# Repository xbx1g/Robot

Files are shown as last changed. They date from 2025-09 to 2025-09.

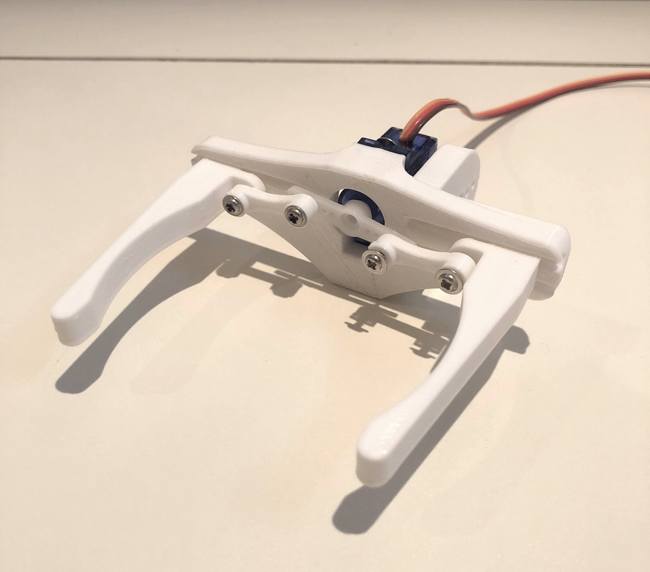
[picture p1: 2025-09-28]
3D_Modeli/VER2/linear-gripper-1.snapshot.4/Finished Build.jpg

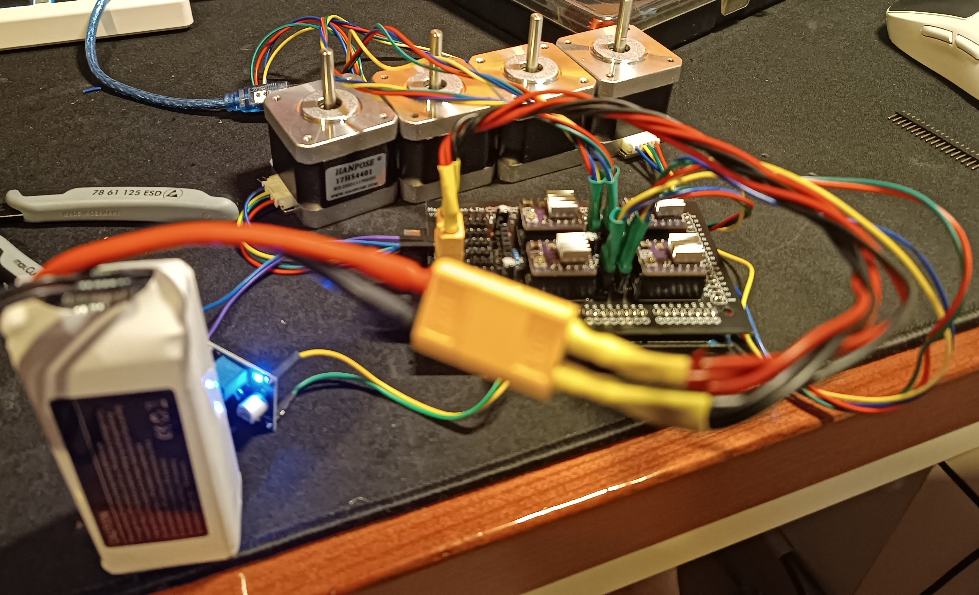
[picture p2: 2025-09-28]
Slike/final_test_baterija_3300mAh.jpg

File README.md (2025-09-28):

# 🤖 Robotic Arm with Mecanum Wheels

This project is a **final thesis** for the vocational matura exam.  
It is a mobile robot with **mecanum wheels** and a **robotic arm**, controllable via **Bluetooth** using a custom mobile app.  
The project combines **mechanical engineering, electronics, and programming** – from CAD design and 3D printing, to PCB design, Arduino programming, and mobile app development.

---

## 📌 Features

- Omni-directional movement with **mecanum wheels**  
- **Robotic arm** with multiple degrees of freedom (servo motors)  
- Custom-designed **PCB** for component management  
- **Arduino Mega 2560** as the main controller  
- Control via **Bluetooth module HC-05** and a mobile app (MIT App Inventor)  
- **3D-printed parts** made from PETG filament  
- Powered and tested with **11.1V 3300 mAh LiPo battery**  

---

## 🛠️ Components Used

- Arduino Mega 2560  
- Servo motors (MG996R, SG90)  
- Bipolar stepper motors + **DRV8825 drivers**  
- Bluetooth module **HC-05**  
- Voltage regulator **LM2596**  
- Custom-designed **PCB** (Eagle CAD)  
- 3D-printed parts (Autodesk Inventor + PrusaSlicer, Ender 3 S1 printer)  

---

## 📱 Mobile App

Developed with **MIT App Inventor**.  
Main features:  
- Control of chassis movement (forward/backward/left/right/diagonal)  
- Control of robotic arm (individual joints)  
- Save and execute movement sequences  
- Adjust motor speeds  

---

## 💻 Arduino Code

The Arduino firmware is organized into several modules:  
- **Main program** (initialization, Bluetooth connection)  
- **Chassis movement control**  
- **Robotic arm control**  
- **Movement sequence storage and execution**  
- **Battery voltage monitoring** with LED warning  

---

## 🚀 Getting Started

1. Assemble the robot (chassis, arm, PCB, and wiring).  
2. Upload the Arduino code to **Arduino Mega 2560**.  
3. Install the mobile app (APK) on your smartphone.  
4. Pair with the **HC-05 Bluetooth module**.  
5. Start controlling the robot and test the functionalities.  

---

## 📊 Testing Results

- Battery runtime: ~30 minutes  
- Stepper motor driver temperature after 30 minutes: **45–55 °C**  
- Robot successfully performs omni-directional movements and basic manipulation tasks  

---

## 🔮 Future Improvements

- Add **LCD display** for battery monitoring and step sequence display  
- Support for **Xbox / other Bluetooth controllers**  
- Further PCB optimization and cable management  

---

## 👤 Author

**Marko Koren**  
Mentor: **Peter Zoroja**  
Šolski center Nova Gorica, 2024

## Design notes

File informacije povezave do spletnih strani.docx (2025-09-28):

Spletne strani, informacije:

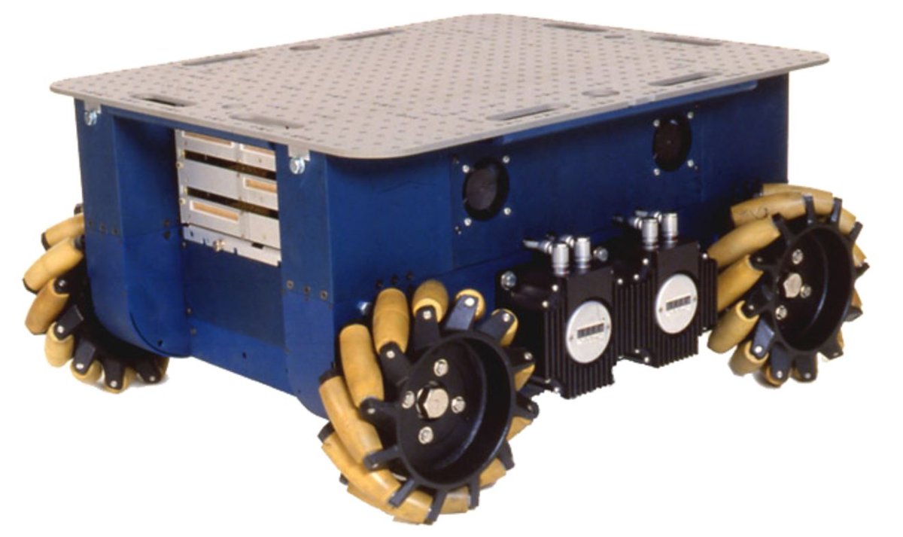
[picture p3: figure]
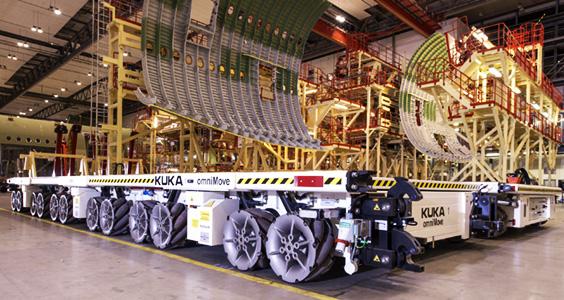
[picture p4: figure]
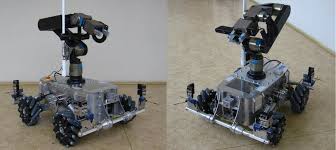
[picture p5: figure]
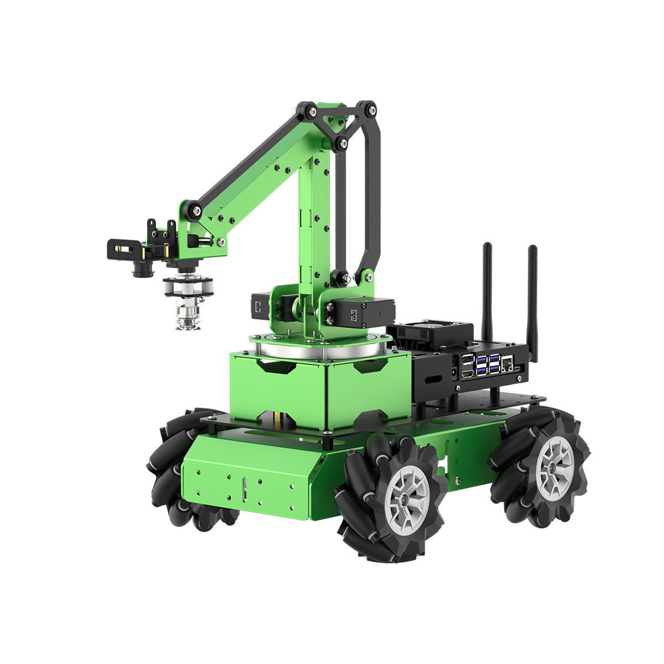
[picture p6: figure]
Hiwonder JetMax Pro JETSON NANO Robot Arm with Mecanum Wheel Chassis/

https://www.youtube.com/watch?v=noqBUEgyQ8A&t=275s

https://www.youtube.com/watch?v=83tVkgT89dM&t=549s

https://www.youtube.com/watch?v=8qtVhCtRoDY&t=21s

https://www.youtube.com/watch?v=Q3pCpVepCxk&t=608s

https://www.youtube.com/watch?v=LBNRGBY5zN8&t=453s&pp=ygUObWVjYW51bSB3aGVlbHM%3D

https://www.youtube.com/shorts/dnPcnVE-7ag

https://www.youtube.com/watch?v=I0Qm7qgqeLU

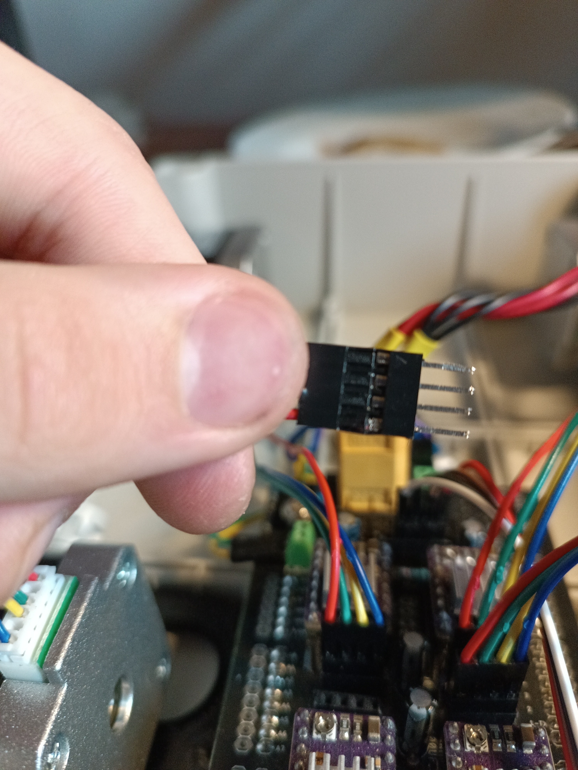
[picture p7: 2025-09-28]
Slike/Konektorj_stepper_motor.jpg

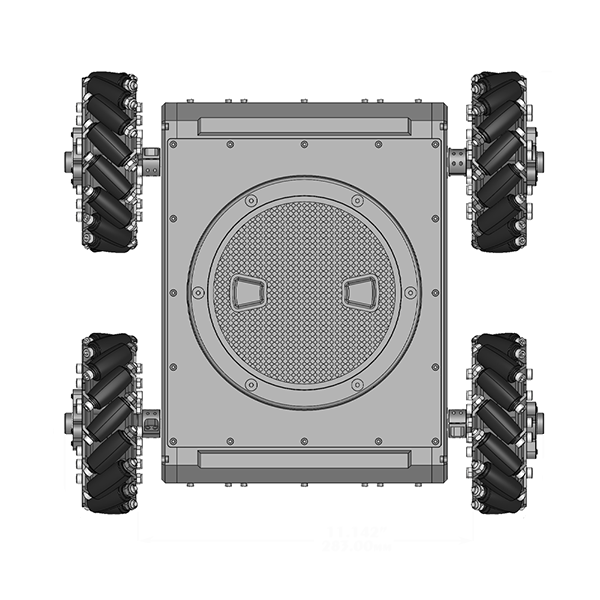
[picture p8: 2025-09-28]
Aplikacija/APP INVENTRO/ROVER.png

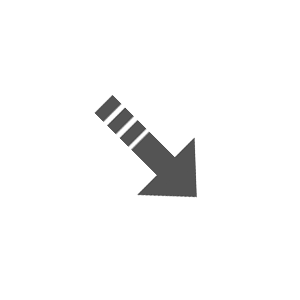
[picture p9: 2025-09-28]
Aplikacija/APP INVENTRO/desnodol.png

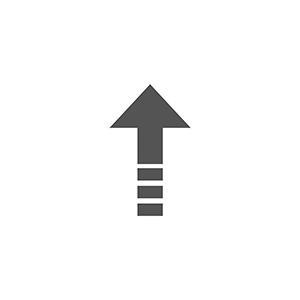
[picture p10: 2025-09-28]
Aplikacija/APP INVENTRO/puscica gor.png

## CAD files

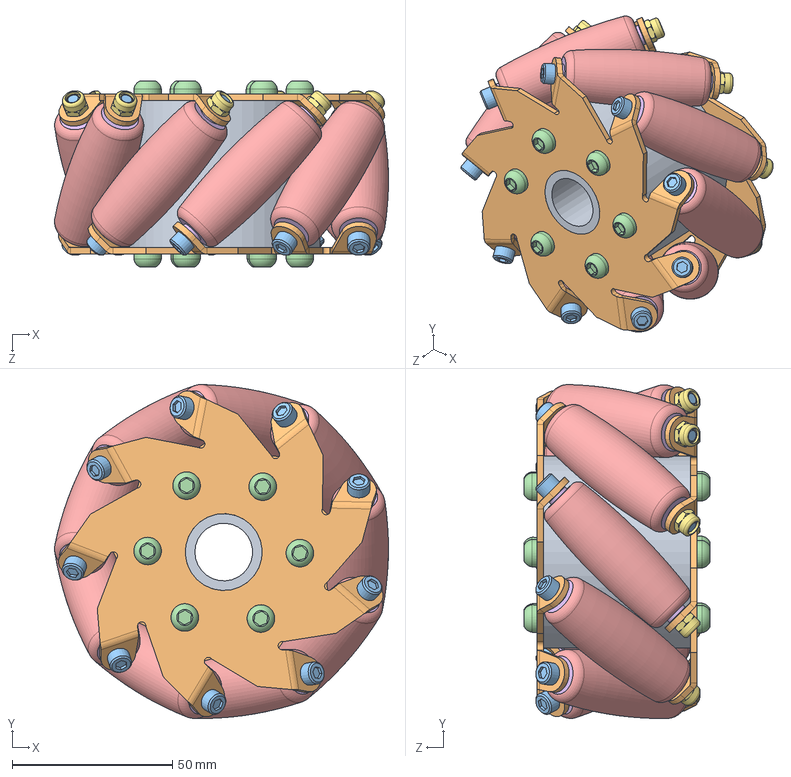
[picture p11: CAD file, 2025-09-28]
3D_Modeli/Robotska_roka/mecanum-wheel-diameter-100mm-right-1.snapshot.1/Mecanum Wheel (dia 100) Right/Assembly/Mecanum Wheel Assembly.SLDASM
104.2 x 104.2 x 58.0 mm
Shaft
Bolt (M3) x 9
Bolt (M5) x 12
Roller x 9
Roller Bracket x 18
torque nut 08_iso x 9

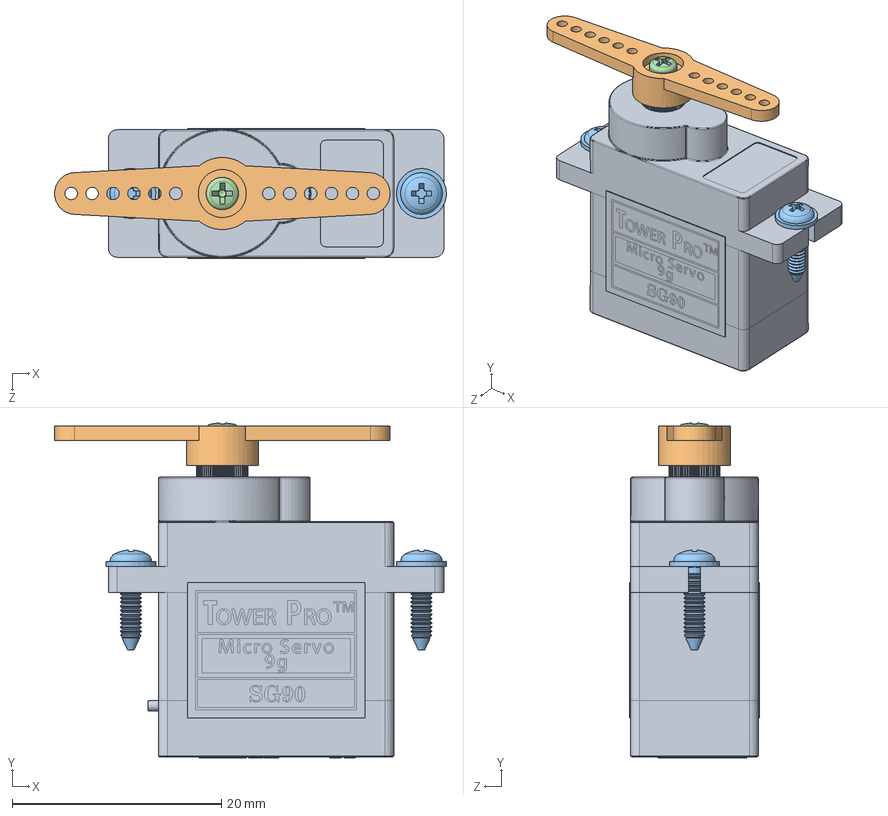
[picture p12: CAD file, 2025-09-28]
3D_Modeli/VER2/sg90-micro-servo-9g-tower-pro-1.snapshot.3/SG90 - Micro Servo 9g - Tower Pro.SLDASM
37.5 x 32.0 x 12.4 mm
SG90 - Micro Servo 9g - Tower Pro.1
SG90 - Micro Servo 9g - Tower Pro.3
SG90 - Micro Servo 9g - Tower Pro.5 x 2
SG90 - Micro Servo 9g - Tower Pro.6

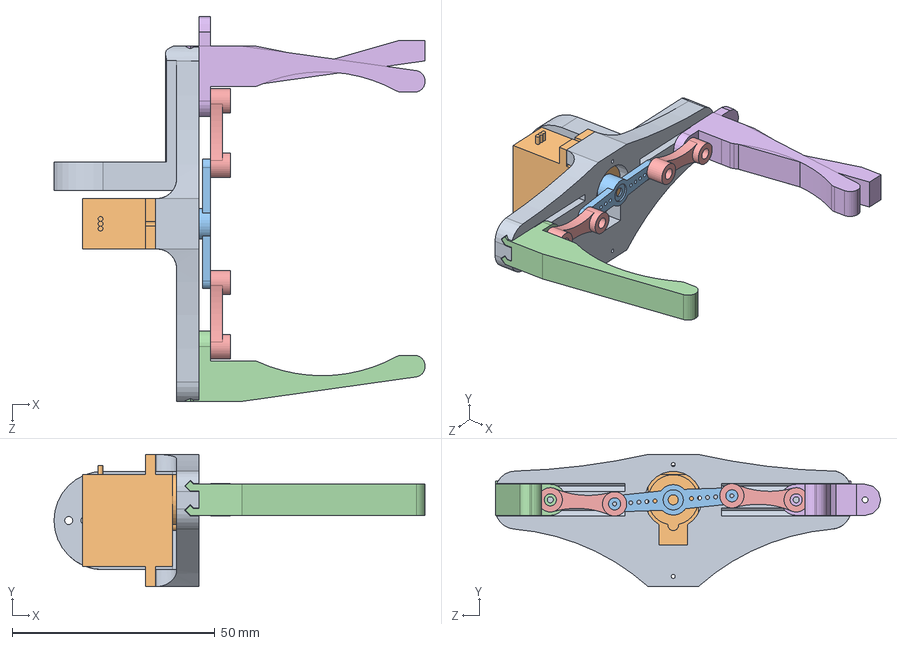
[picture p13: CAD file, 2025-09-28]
3D_Modeli/Robotska_roka/linear-gripper-1.snapshot.4/Linear Gripper.SLDASM
91.5 x 32.6 x 95.1 mm
Linear Base
Servo Micro
Horn
LGrip
Linear Link x 2
LGrip Mirror

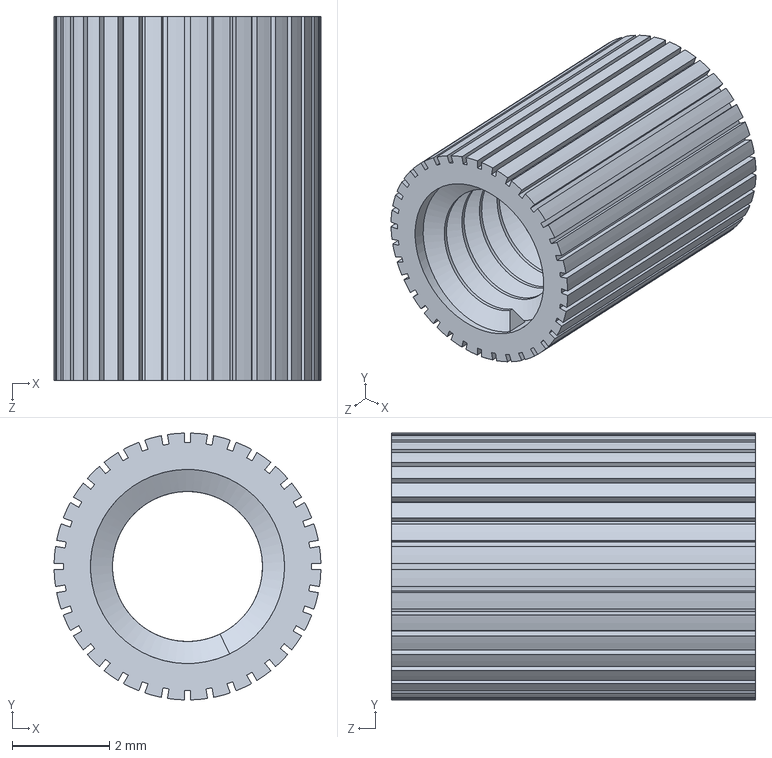
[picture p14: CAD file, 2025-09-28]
3D_Modeli/Robotska_roka/lemotech-ip67-junction-box-250-mm-x-150-mm-x-100-mm-1.snapshot.2/M4 Insert, LeMotech IP67 Junction Box, 250 mm x 150 mm x 100 mm.SLDPRT
5.50 x 5.50 x 7.50 mm

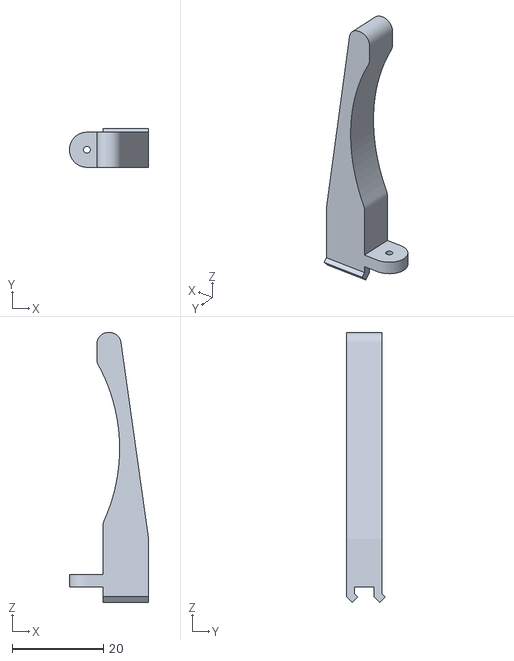
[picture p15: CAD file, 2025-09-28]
3D_Modeli/Robotska_roka/linear-gripper-1.snapshot.4/Linear Gripper/LGrip Mirror.stl
17.4 x 8.47 x 59.1

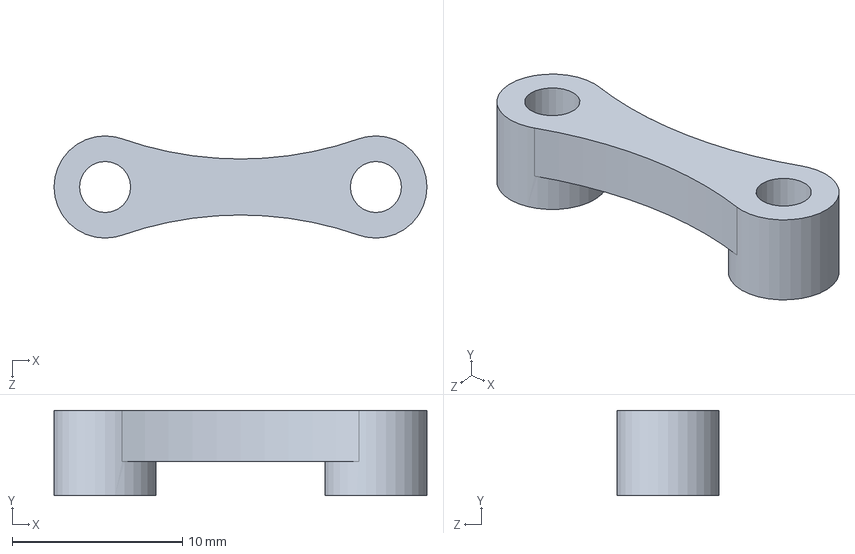
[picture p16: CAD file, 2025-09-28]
3D_Modeli/Robotska_roka/linear-gripper-1.snapshot.4/Linear Link.SLDPRT
21.9 x 5.00 x 6.00 mm

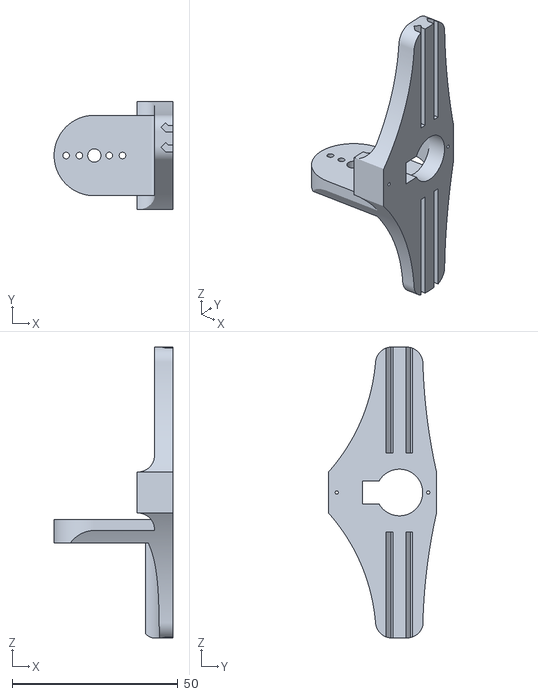
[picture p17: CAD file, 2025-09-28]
3D_Modeli/Robotska_roka/linear-gripper-1.snapshot.4/STL for 3D Printing/Linear Gripper - Linear Base-1.STL
35.8 x 32.6 x 87.8

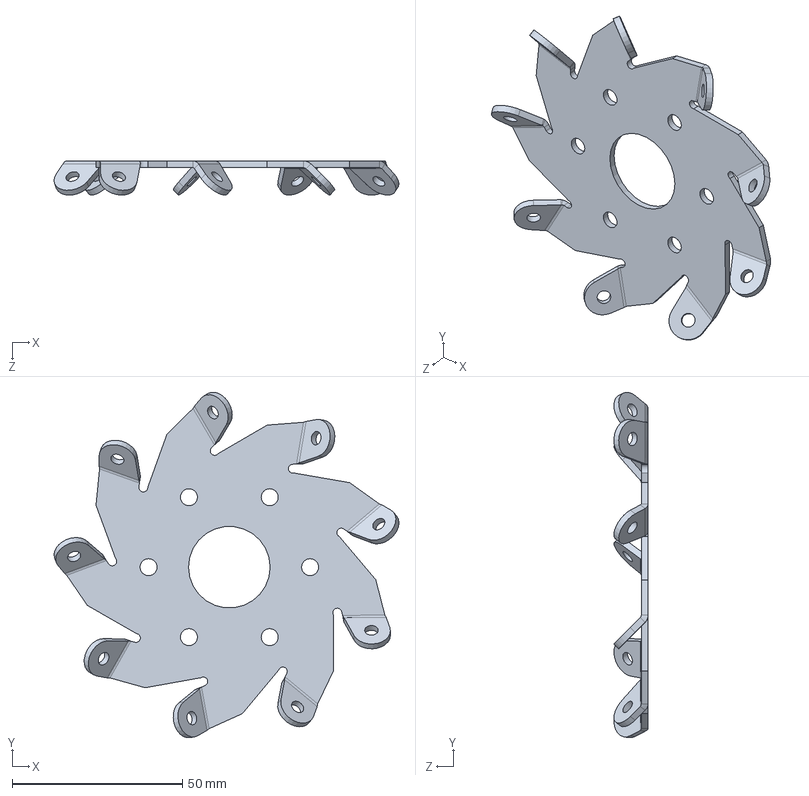
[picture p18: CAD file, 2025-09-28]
3D_Modeli/Robotska_roka/mecanum-wheel-diameter-100mm-right-1.snapshot.1/Mecanum Wheel (dia 100) Right/Components/Body.SLDPRT
101.4 x 101.6 x 10.1 mm

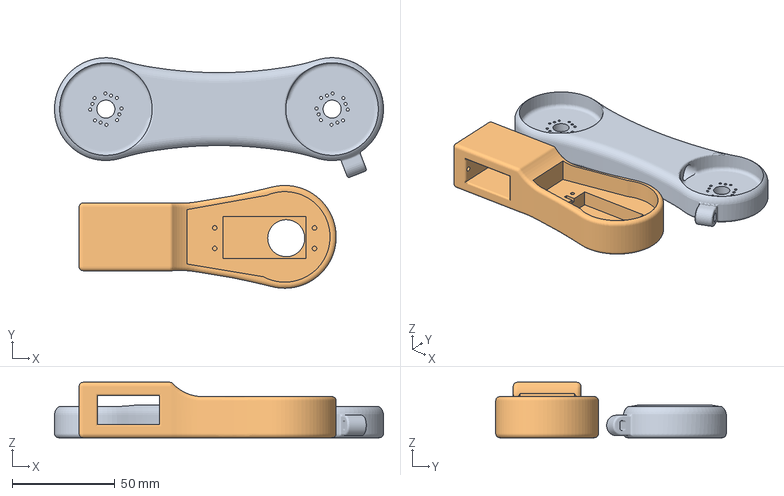
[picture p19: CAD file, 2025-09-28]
3D_Modeli/Robotska_roka/roka1.3mf
160.0 x 112.1 x 27.0 mm
roka1.stl
roka2.stl

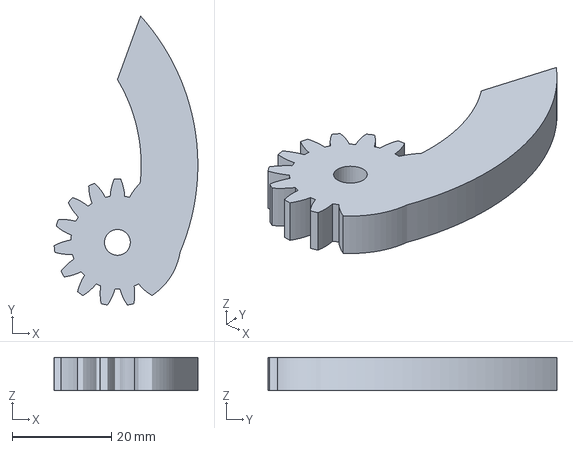
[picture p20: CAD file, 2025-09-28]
3D_Modeli/Robotska_roka/roka_asemb/Design Accelerator/Spur Gear11.3mf
28.9 x 58.1 x 6.67 mm

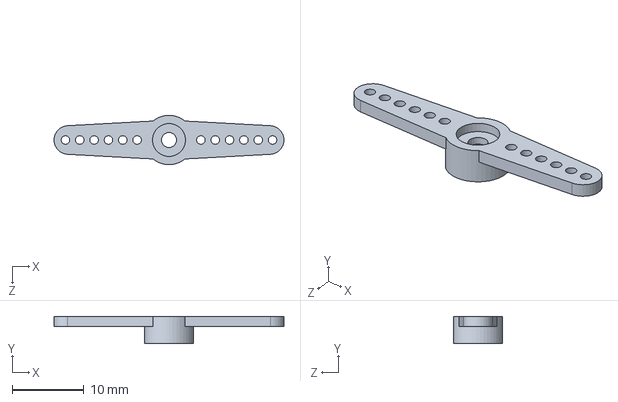
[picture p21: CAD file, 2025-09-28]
3D_Modeli/Robotska_roka/sg90-micro-servo-9g-tower-pro-1.snapshot.3/SG90 - Micro Servo 9g - Tower Pro.3.SLDPRT
32.1 x 3.80 x 6.90 mm

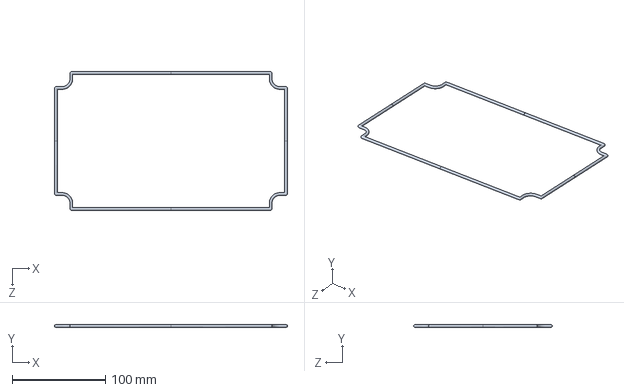
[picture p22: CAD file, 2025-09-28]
3D_Modeli/VER2/lemotech-ip67-junction-box-250-mm-x-150-mm-x-100-mm-1.snapshot.2/O-ring, LeMotech IP67 Junction Box, 250 mm x 150 mm x 100 mm.SLDPRT
249.6 x 3.00 x 148.6 mm

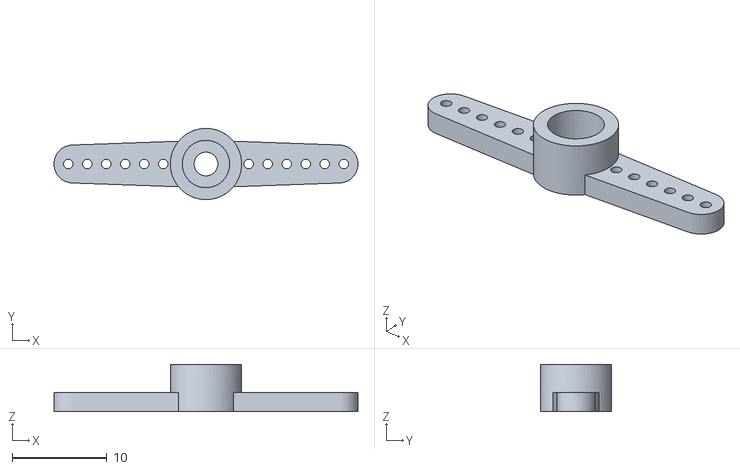
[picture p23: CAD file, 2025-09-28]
3D_Modeli/VER2/linear-gripper-1.snapshot.4/Linear Gripper/Horn.stl
32.0 x 7.50 x 5.00

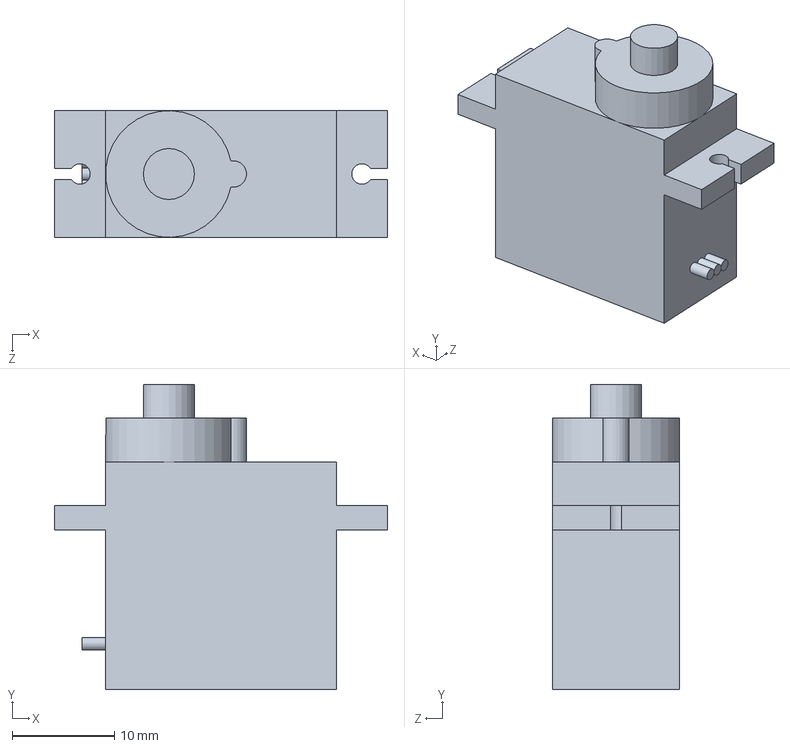
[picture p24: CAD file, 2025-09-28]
3D_Modeli/VER2/linear-gripper-1.snapshot.4/Servo Micro.SLDPRT
32.6 x 29.9 x 12.4 mm

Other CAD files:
3D_Modeli/Robotska_roka/mecanum-wheel-diameter-100mm-right-1.snapshot.1/Mecanum Wheel (dia 100) Right/Mecanum Wheel (dia 100).STEP
3D_Modeli/Robotska_roka/123.stl
3D_Modeli/Robotska_roka/2.ipt
3D_Modeli/Robotska_roka/2.stl
3D_Modeli/Robotska_roka/ArduinoMega_STEP_AP203/ArduinoMega_STEP_AP203.ipt
3D_Modeli/Robotska_roka/OldVersions/2.0003.ipt
3D_Modeli/Robotska_roka/OldVersions/FINAL.0032.iam
3D_Modeli/Robotska_roka/OldVersions/PIN.0080.ipt
3D_Modeli/Robotska_roka/OldVersions/Part2.0011.ipt
3D_Modeli/Robotska_roka/OldVersions/buh.0004.ipt
3D_Modeli/Robotska_roka/OldVersions/buh2.0004.ipt
3D_Modeli/Robotska_roka/OldVersions/miza.0187.ipt
3D_Modeli/Robotska_roka/OldVersions/podloga.0041.ipt
3D_Modeli/Robotska_roka/OldVersions/roka.0076.iam
3D_Modeli/Robotska_roka/OldVersions/roka1.0044.ipt
3D_Modeli/Robotska_roka/OldVersions/roka2.0112.ipt
3D_Modeli/Robotska_roka/OldVersions/roka3.0098.ipt
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

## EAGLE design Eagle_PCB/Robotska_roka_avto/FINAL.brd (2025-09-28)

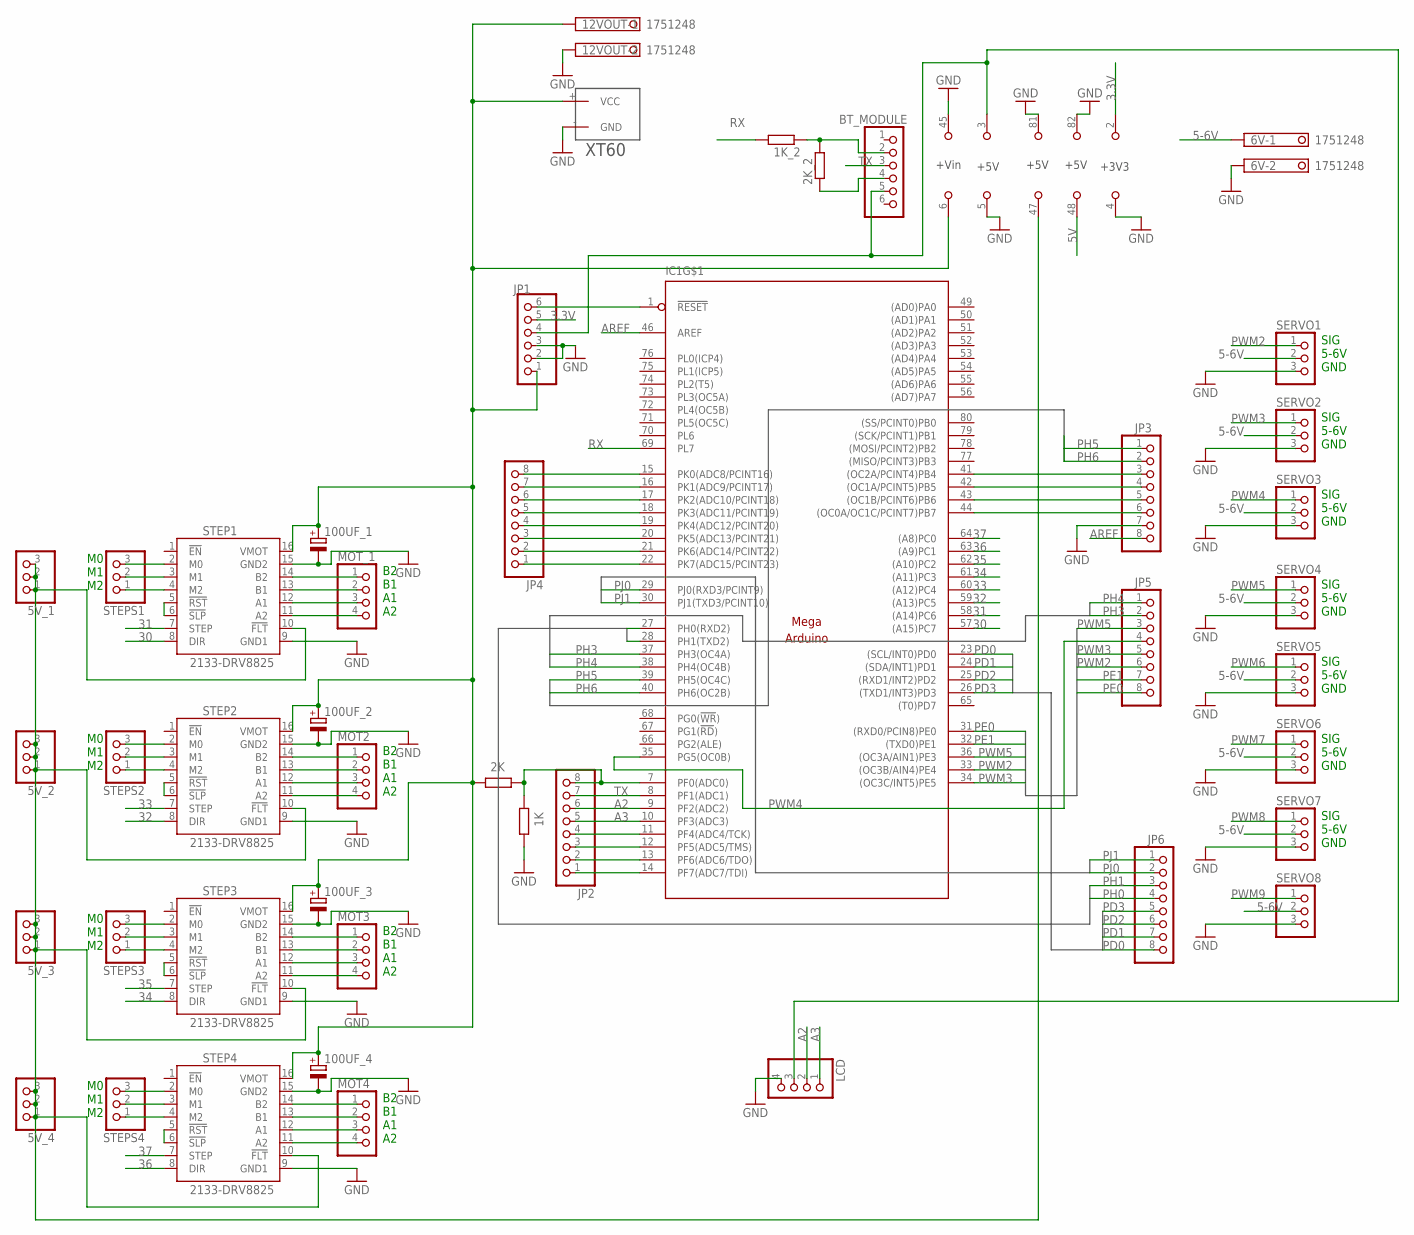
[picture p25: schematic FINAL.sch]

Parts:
1K, 1K_2, 2K, 2K_2: R-EU_0204/7; 0204/7
5V_1, 5V_2, 5V_3, 5V_4: PINHD-1X3; 1X03
6V, 12VOUT: 1751248
100UF_1, 100UF_2, 100UF_3, 100UF_4: CPOL-EUE5-5; E5-5
BT_MODULE: PINHD-1X6; 1X06
IC1: MEGAARDUINO_22; MEGA_ARDUINO_2
JP1: PINHD-1X6; 1X06
JP2, JP3, JP4, JP5, JP6: PINHD-1X8; 1X08
LCD: PINHD-1X4; 1X04
MOT2, MOT3, MOT4: PINHD-1X4; 1X04
MOT_1: PINHD-1X4; 1X04
SERVO1, SERVO2, SERVO3, SERVO4, SERVO5, SERVO6, SERVO7, SERVO8: PINHD-1X3; 1X03
STEP1, STEP2, STEP3, STEP4: 2133-DRV8825; DRV8825
STEPS1, STEPS2, STEPS3, STEPS4: PINHD-1X3; 1X03
U$1: XT60

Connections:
3.3V: IC1.2 (+3V3), JP1.5
5-6V: 6V.1, SERVO1.2, SERVO2.2, SERVO3.2, SERVO4.2, SERVO5.2, SERVO6.2, SERVO7.2, SERVO8.2
5V: IC1.48 (+5V)
12V1: 2K.1, 12VOUT.1, 100UF_1.+, 100UF_2.+, 100UF_3.+, 100UF_4.+, IC1.6 (+VIN), JP1.1, STEP1.16 (VMOT), STEP2.16 (VMOT), STEP3.16 (VMOT), STEP4.16 (VMOT), U$1.+ (VCC)
30: IC1.57 ((A15)PC7), STEP1.8 (DIR)
31: IC1.58 ((A14)PC6), STEP1.7 (STEP)
32: IC1.59 ((A13)PC5), STEP2.8 (DIR)
33: IC1.60 ((A12)PC4), STEP2.7 (STEP)
34: IC1.61 ((A11)PC3), STEP3.8 (DIR)
35: IC1.62 ((A10)PC2), STEP3.7 (STEP)
36: IC1.63 ((A9)PC1), STEP4.8 (DIR)
37: IC1.64 ((A8)PC0), STEP4.7 (STEP)
A2: IC1.9 (PF2(ADC2)), JP2.6, LCD.2
A3: IC1.10 (PF3(ADC3)), JP2.5, LCD.1
AREF: IC1.46 (AREF), JP3.8
GND: 1K.2, 6V.2, 12VOUT.2, 100UF_1.-, 100UF_2.-, 100UF_3.-, 100UF_4.-, IC1.4 (GND), IC1.5 (GND), IC1.45 (GND), IC1.81 (GND), IC1.82 (GND), JP1.2, JP1.3, JP3.7, LCD.4, SERVO1.3, SERVO2.3, SERVO3.3, SERVO4.3, SERVO5.3, SERVO6.3, SERVO7.3, SERVO8.3, STEP1.9 (GND1), STEP1.15 (GND2), STEP2.9 (GND1), STEP2.15 (GND2), STEP3.9 (GND1), STEP3.15 (GND2), STEP4.9 (GND1), STEP4.15 (GND2), U$1.- (GND)
unnamed: IC1.11 (PF4(ADC4/TCK)), JP2.4
unnamed: MOT_1.1, STEP1.14 (B2)
unnamed: MOT_1.2, STEP1.13 (B1)
unnamed: MOT_1.3, STEP1.12 (A1)
unnamed: MOT_1.4, STEP1.11 (A2)
unnamed: MOT2.1, STEP2.14 (B2)
unnamed: MOT2.2, STEP2.13 (B1)
unnamed: MOT2.3, STEP2.12 (A1)
unnamed: MOT2.4, STEP2.11 (A2)
unnamed: MOT3.1, STEP3.14 (B2)
unnamed: MOT3.2, STEP3.13 (B1)
unnamed: MOT3.3, STEP3.12 (A1)
unnamed: MOT3.4, STEP3.11 (A2)
unnamed: MOT4.1, STEP4.14 (B2)
unnamed: MOT4.2, STEP4.13 (B1)
unnamed: MOT4.3, STEP4.12 (A1)
unnamed: MOT4.4, STEP4.11 (A2)
unnamed: STEP1.2 (M0), STEPS1.3
unnamed: 2K_2.1, BT_MODULE.4
unnamed: 1K_2.1, 2K_2.2, BT_MODULE.2
unnamed: STEP1.3 (M1), STEPS1.2
unnamed: STEP1.4 (M2), STEPS1.1
unnamed: STEP2.2 (M0), STEPS2.3
unnamed: STEP2.3 (M1), STEPS2.2
unnamed: STEP2.4 (M2), STEPS2.1
unnamed: STEP3.2 (M0), STEPS3.3
unnamed: STEP3.3 (M1), STEPS3.2
unnamed: STEP3.4 (M2), STEPS3.1
unnamed: STEP4.2 (M0), STEPS4.3
unnamed: STEP4.3 (M1), STEPS4.2
unnamed: STEP4.4 (M2), STEPS4.1
unnamed: STEP1.5 (!RST), STEP1.6 (!SLP)
unnamed: STEP2.5 (!RST), STEP2.6 (!SLP)
unnamed: STEP3.5 (!RST), STEP3.6 (!SLP)
unnamed: STEP4.5 (!RST), STEP4.6 (!SLP)
unnamed: 5V_1.1, 5V_1.2, 5V_1.3, 5V_2.1, 5V_2.2, 5V_2.3, 5V_3.1, 5V_3.2, 5V_3.3, 5V_4.1, 5V_4.2, 5V_4.3, IC1.47 (+5V), STEP1.10 (!FLT), STEP2.10 (!FLT), STEP3.10 (!FLT), STEP4.10 (!FLT)
unnamed: IC1.1 (!RESET), JP1.6
unnamed: 1K.1, 2K.2, IC1.7 (PF0(ADC0)), JP2.8
unnamed: IC1.12 (PF5(ADC5/TMS)), JP2.3
unnamed: IC1.13 (PF6(ADC6/TDO)), JP2.2
unnamed: IC1.14 (PF7(ADC7/TDI)), JP2.1
unnamed: IC1.15 (PK0(ADC8/PCINT16)), JP4.8
unnamed: IC1.16 (PK1(ADC9/PCINT17)), JP4.7
unnamed: IC1.17 (PK2(ADC10/PCINT18)), JP4.6
unnamed: IC1.18 (PK3(ADC11/PCINT19)), JP4.5
unnamed: IC1.19 (PK4(ADC12/PCINT20)), JP4.4
unnamed: IC1.20 (PK5(ADC13/PCINT21)), JP4.3
unnamed: IC1.21 (PK6(ADC14/PCINT22)), JP4.2
unnamed: IC1.22 (PK7(ADC15/PCINT23)), JP4.1
unnamed: IC1.44 ((OC0A/OC1C/PCINT7)PB7), JP3.6
unnamed: IC1.43 ((OC1B/PCINT6)PB6), JP3.5
unnamed: IC1.42 ((OC1A/PCINT5)PB5), JP3.4
unnamed: IC1.41 ((OC2A/PCINT4)PB4), JP3.3
unnamed: BT_MODULE.5, IC1.3 (+5V), JP1.4, LCD.3
PD0: IC1.23 ((SCL/INT0)PD0), JP6.8
PD1: IC1.24 ((SDA/INT1)PD1), JP6.7
PD2: IC1.25 ((RXD1/INT2)PD2), JP6.6
PD3: IC1.26 ((TXD1/INT3)PD3), JP6.5
PE0: IC1.31 ((RXD0/PCIN8)PE0), JP5.8
PE1: IC1.32 ((TXD0)PE1), JP5.7
PH0: IC1.27 (PH0(RXD2)), JP6.4
PH1: IC1.28 (PH1(TXD2)), JP6.3
PH3: IC1.37 (PH3(OC4A)), JP5.2
PH4: IC1.38 (PH4(OC4B)), JP5.1
PH5: IC1.39 (PH5(OC4C)), JP3.1
PH6: IC1.40 (PH6(OC2B)), JP3.2
PJ0: IC1.29 (PJ0(RXD3/PCINT9)), JP6.2
PJ1: IC1.30 (PJ1(TXD3/PCINT10)), JP6.1
PWM2: IC1.33 ((OC3B/AIN4)PE4), JP5.6, SERVO1.1
PWM3: IC1.34 ((OC3C/INT5)PE5), JP5.5, SERVO2.1
PWM4: IC1.35 (PG5(OC0B)), JP5.4, SERVO3.1
PWM5: IC1.36 ((OC3A/AIN1)PE3), JP5.3, SERVO4.1
PWM6: SERVO5.1
PWM7: SERVO6.1
PWM8: SERVO7.1
PWM9: SERVO8.1
RX: 1K_2.2, IC1.69 (PL7)
TX: BT_MODULE.3, IC1.8 (PF1(ADC1)), JP2.7

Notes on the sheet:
B2 B1 A1 A2
M0 M1 M2
SIG 5-6V GND

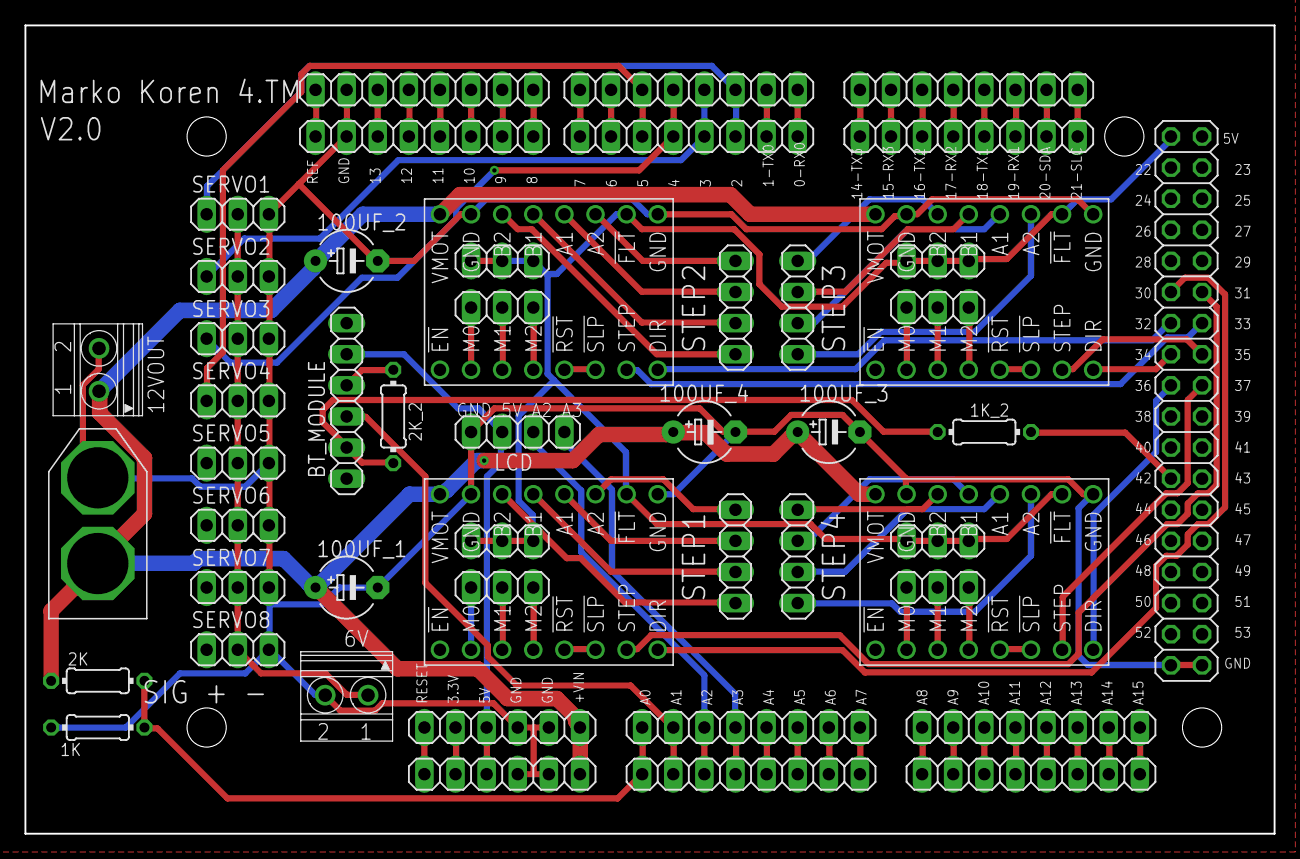
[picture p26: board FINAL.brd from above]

Board: 2 copper layers, 102.0 x 66.0 mm, 44 parts (0 on the bottom side), 89 nets.

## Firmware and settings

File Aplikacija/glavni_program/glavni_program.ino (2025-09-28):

#include <SoftwareSerial.h>             // uvoz knjižnic v arduino program
#include <AccelStepper.h>
#include <Servo.h>
#include <LiquidCrystal_I2C.h>


Servo Servo_baza;                       // Imena sklopov robota
Servo Servo_rama;
Servo Servo_komolec;
Servo Servo_rotacija;
Servo Servo_gripper_premik;
Servo Servo_gripper_stisk;

SoftwareSerial BT(A8, 42); // Arduino(RX, TX) - HC-05 BT (TX, RX)
AccelStepper LevoZadajKolo(1, 37, 36);   // Koračni motor 1   (vrsta krmilnika koračnega motorja, DIR, STEP)
AccelStepper LevoSpredajKolo(1, 31, 30);  // Koračni motor 2
AccelStepper DesnoZadajKolo(1, 35, 34);  // Koračni motor 3
AccelStepper DesnoSpredajKolo(1, 33, 32); // Koračni motor 4

#define led 14          // led dioda za ponazoritev prazne baterije

int hitrostKoles = 2000;

int lbw[50], lfw[50], rbw[50], rfw[50]; // polja za shranjevanje pozicij/korakov

int Servo_bazaPos, Servo_ramaPos, Servo_komolecPos, Servo_rotacijaPos, Servo_gripper_premikPos, Servo_gripper_stiskPos; // trenutna pozicija
int Servo_bazaPPos, Servo_ramaPPos, Servo_komolecPPos, Servo_rotacijaPPos, Servo_gripper_premikPPos, Servo_gripper_stiskPPos; // prejšna pozicija
int Servo_bazaSP[50], Servo_ramaSP[50], Servo_komolecSP[50], Servo_rotacijaSP[50], Servo_gripper_premikSP[50], Servo_gripper_stiskSP[50]; // polja za shranjevanje pozicij/korakov servo motorjev
int speedDelay = 20;
int index = 0;
int dataIn;
int korak = 0;

void setup() {
  // Začetna hitrost koračnih motorjev
  LevoSpredajKolo.setMaxSpeed(1000);
  LevoZadajKolo.setMaxSpeed(1000);
  DesnoSpredajKolo.setMaxSpeed(1000);
  DesnoZadajKolo.setMaxSpeed(1000);
  pinMode(led, OUTPUT);
  Servo_baza.attach(2);
  Servo_rama.attach(3);
  Servo_komolec.attach(4);
  Servo_rotacija.attach(5);
  Servo_gripper_premik.attach(6);
  Servo_gripper_stisk.attach(7);
  BT.begin(38400); // Privzeta hitrost prenosa modula HC-05
  BT.setTimeout(5);
  delay(20);
  Serial.begin(38400);

  // Premik robotske roke na začetno pozicijo
  Servo_bazaPPos = 95;
  Servo_baza.write(Servo_bazaPPos);
  Servo_ramaPPos = 90;
  Servo_rama.write(Servo_ramaPPos);
  Servo_komolecPPos = 180;
  Servo_komolec.write(Servo_komolecPPos);
  Servo_rotacijaPPos = 95;
  Servo_rotacija.write(Servo_rotacijaPPos);
  Servo_gripper_premikPPos = 80;
  Servo_gripper_premik.write(Servo_gripper_premikPPos);
  Servo_gripper_stiskPPos = 90;
  Servo_gripper_stisk.write(Servo_gripper_stiskPPos);
}

void loop() {
  // Preveri prihajajoče podatke
  if (BT.available() > 0) {
    preimenovanje();
    koraki();
    roka();
    pozicije();
  }
  LevoSpredajKolo.runSpeed(); 
  LevoZadajKolo.runSpeed();
  DesnoSpredajKolo.runSpeed();
  DesnoZadajKolo.runSpeed();

  // Napetost baterije
  int sensorValue = analogRead(A0);
  float napetost = sensorValue * (5.0 / 1023.00) * 3; // pretvori 5V v 12V za branje napetosti baterije
  // Če napetost pade pod 11V se bo lučka prižgala
  if (napetost < 11.6) {
    digitalWrite(led, HIGH);
  }
  else {
    digitalWrite(led, LOW);
  }
}

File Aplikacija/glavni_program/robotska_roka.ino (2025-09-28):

void roka() {
  // Premik servo 1 v plus smer
  while (korak == 16) {
    if (BT.available() > 0) {
      korak = BT.read();
    }
    Servo_baza.write(Servo_bazaPPos);
    Servo_bazaPPos++;
    delay(speedDelay);
  }
  // Premik servo 1 v minus smer
  while (korak == 17) {
    if (BT.available() > 0) {
      korak = BT.read();
    }
    Servo_baza.write(Servo_bazaPPos);
    Servo_bazaPPos--;
    delay(speedDelay);
  }
  // Move servo 2
  while (korak == 19) {
    if (BT.available() > 0) {
      korak = BT.read();
    }
    Servo_rama.write(Servo_ramaPPos);
    Servo_ramaPPos++;
    delay(speedDelay);
  }
  while (korak == 18) {
    if (BT.available() > 0) {
      korak = BT.read();
    }
    Servo_rama.write(Servo_ramaPPos);
    Servo_ramaPPos--;
    delay(speedDelay);
  }
  // Move servo 3
  while (korak == 20) {
    if (BT.available() > 0) {
      korak = BT.read();
    }
    Servo_komolec.write(Servo_komolecPPos);
    Servo_komolecPPos++;
    delay(speedDelay);
  }
  while (korak == 21) {
    if (BT.available() > 0) {
      korak = BT.read();
    }
    Servo_komolec.write(Servo_komolecPPos);
    Servo_komolecPPos--;
    delay(speedDelay);
  }
  // Move servo 4
  while (korak == 23) {
    if (BT.available() > 0) {
      korak = BT.read();
    }
    Servo_rotacija.write(Servo_rotacijaPPos);
    Servo_rotacijaPPos++;
    delay(speedDelay);
  }
  while (korak == 22) {
    if (BT.available() > 0) {
      korak = BT.read();
    }
    Servo_rotacija.write(Servo_rotacijaPPos);
    Servo_rotacijaPPos--;
    delay(speedDelay);
  }
  // Move servo 5
  while (korak == 25) {
    if (BT.available() > 0) {
      korak = BT.read();
    }
    Servo_gripper_premik.write(Servo_gripper_premikPPos);
    Servo_gripper_premikPPos++;
    delay(speedDelay);
  }
  while (korak == 24) {
    if (BT.available() > 0) {
      korak = BT.read();
    }
    Servo_gripper_premik.write(Servo_gripper_premikPPos);
    Servo_gripper_premikPPos--;
    delay(speedDelay);
  }
  // Move servo 6
  while (korak == 26) {
    if (BT.available() > 0) {
      korak = BT.read();
    }
    Servo_gripper_stisk.write(Servo_gripper_stiskPPos);
    Servo_gripper_stiskPPos++;
    delay(speedDelay);
  }
  while (korak == 27) {
    if (BT.available() > 0) {
      korak = BT.read();
    }
    Servo_gripper_stisk.write(Servo_gripper_stiskPPos);
    Servo_gripper_stiskPPos--;
    delay(speedDelay);
  }

  // Hitrost robotske roke
  if (dataIn > 101 & dataIn < 250) {
    speedDelay = dataIn / 10; // Change servo speed (delay time)
  }
}
